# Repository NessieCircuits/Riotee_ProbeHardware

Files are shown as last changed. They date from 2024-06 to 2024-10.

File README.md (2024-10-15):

# Riotee Probe Hardware Design Files



The Riotee probe lets you program a Riotee module that is soldered onto your PCB or plugged into a breadboard. It has a standard 10-pin 0.1" connector compatible with the popular Tag-Connect cables that allow in-circuit debugging with a very small footprint.

Latest design files:
 - [Schematics](https://www.riotee.nessie-circuits.de/artifacts/probe_hardware/latest/schematics.pdf)
 - [Layout](https://www.riotee.nessie-circuits.de/artifacts/probe_hardware/latest/pcb.pdf)
 - [Assembly plan](https://www.riotee.nessie-circuits.de/artifacts/probe_hardware/latest/assembly.pdf)
 - [3D rendering](https://www.riotee.nessie-circuits.de/artifacts/probe_hardware/latest/3drendering.png)
 - [Gerber](https://www.riotee.nessie-circuits.de/artifacts/probe_hardware/latest/gerber.zip)
 - [BOM](https://www.riotee.nessie-circuits.de/artifacts/probe_hardware/latest/bom.csv)

Specification:
 - Custom debug probe for in-circuit programming/debugging of Riotee modules
 - USB-C connector for connection to a PC
 - Raspberry Pi RP2040 controller handles programming/debugging
 - CMSIS-DAP compatible: Supports programming of the Riotee module via pyOCD/OpenOCD
 - Makes UART output from Riotee module available via USB

Rendering of Riotee probe Riotee probe

## Firmware

The probe has a dedicated controller (Raspberry Pi RP2040) that manages the upload of new firmware to the Riotee device as well as the communication with a PC. The firmware running on the RP2040 is hosted in [this repository](https://github.com/NessieCircuits/Riotee_ProbeFirmware). To upgrade the firmware on the Riotee probe, connect a wire from one of the ground pins to the test pad labelled 'USB_BOOT' on the bottom of the board, while plugging in the USB cable. A removable storage drive should appear on your PC. Drop a UF2 compatible binary into the drive.

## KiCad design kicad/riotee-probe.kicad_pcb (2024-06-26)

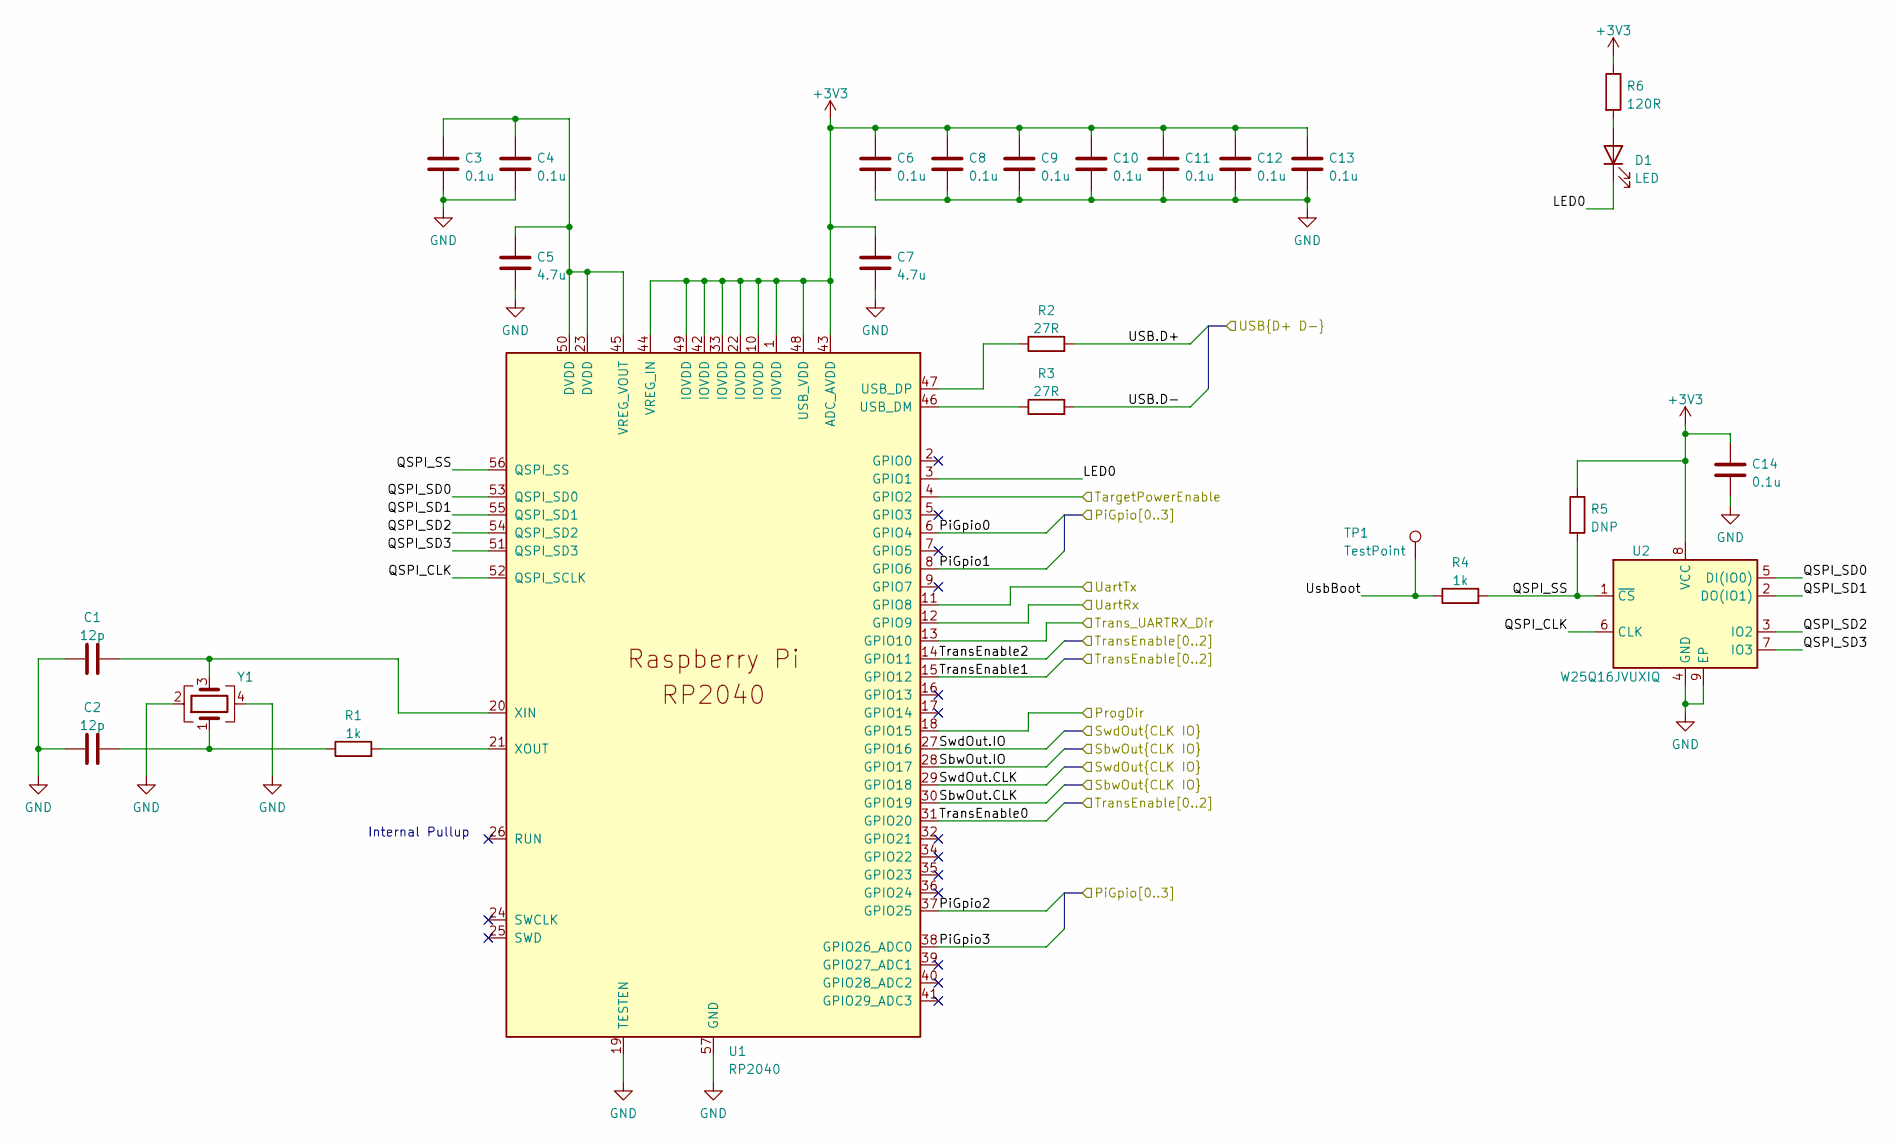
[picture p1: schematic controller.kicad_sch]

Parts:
C1, C2: 12p; C_0402_1005Metric; MPN 04025A120JAT2A
C3, C4, C6, C8, C9, C10, C11, C12, C13, C14: 0.1u; C_0402_1005Metric; MPN CL05A104KA5NNNC
C5, C7: 4.7u; C_0402_1005Metric; MPN CL05A475MP5NRNC
D1: LED; LED_0402_1005Metric; MPN QBLP595-AG1
R1, R4: 1k; R_0402_1005Metric; MPN WR04X1001FTL
R2, R3: 27R; R_0402_1005Metric; MPN CR0402-FX-27R0GLF
R5: DNP; R_0402_1005Metric
R6: 120R; R_0402_1005Metric; MPN CR0402-FX-1200GLF
TP1: TestPoint; TestPoint_Pad_D1.0mm
U1: RP2040; RP_RP2040; MPN RP2040
U2: W25Q16JVUXIQ; WB_UX8; MPN W25Q16JVUXIQ
Y1: Crystal_GND24; RALTRON_RH100; MPN RH100-12.000-18-2030-TR

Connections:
+3V3: C6.1, C7.1, C8.1, C9.1, C10.1, C11.1, C12.1, C13.1, C14.1, R5.1, R6.1, U1.1 (IOVDD), U1.10 (IOVDD), U1.22 (IOVDD), U1.33 (IOVDD), U1.42 (IOVDD), U1.43 (ADC_AVDD), U1.44 (VREG_IN), U1.48 (USB_VDD), U1.49 (IOVDD), U2.8 (VCC); also elsewhere on the board
/Connectors/PiGpio0: U1.6 (GPIO4); also elsewhere on the board
/Connectors/PiGpio1: U1.8 (GPIO6); also elsewhere on the board
/Connectors/PiGpio2: U1.37 (GPIO25); also elsewhere on the board
/Connectors/PiGpio3: U1.38 (GPIO26_ADC0); also elsewhere on the board
/Connectors/TargetPowerEnable: U1.4 (GPIO2); also elsewhere on the board
/Controller/LED0: D1.1 (K), U1.3 (GPIO1)
/Controller/ProgDir: U1.18 (GPIO15); also elsewhere on the board
/Controller/QSPI_CLK: U1.52 (QSPI_SCLK), U2.6 (CLK)
/Controller/QSPI_SD0: U1.53 (QSPI_SD0), U2.5 (DI(IO0))
/Controller/QSPI_SD1: U1.55 (QSPI_SD1), U2.2 (DO(IO1))
/Controller/QSPI_SD2: U1.54 (QSPI_SD2), U2.3 (IO2)
/Controller/QSPI_SD3: U1.51 (QSPI_SD3), U2.7 (IO3)
/Controller/QSPI_SS: R4.2, R5.2, U1.56 (QSPI_SS), U2.1 (~CS)
/Controller/SbwOut.CLK: U1.30 (GPIO19); also elsewhere on the board
/Controller/SbwOut.IO: U1.28 (GPIO17); also elsewhere on the board
/Controller/SwdOut.CLK: U1.29 (GPIO18); also elsewhere on the board
/Controller/SwdOut.IO: U1.27 (GPIO16); also elsewhere on the board
/Controller/TransEnable0: U1.31 (GPIO20); also elsewhere on the board
/Controller/TransEnable1: U1.15 (GPIO12); also elsewhere on the board
/Controller/TransEnable2: U1.14 (GPIO11); also elsewhere on the board
/Controller/Trans_UARTRX_Dir: U1.13 (GPIO10); also elsewhere on the board
/Controller/USB.D+: R2.2; also elsewhere on the board
/Controller/USB.D-: R3.2; also elsewhere on the board
/Controller/UartRx: U1.12 (GPIO9); also elsewhere on the board
/Controller/UartTx: U1.11 (GPIO8); also elsewhere on the board
/Controller/UsbBoot: R4.1, TP1.1
GND: C1.1, C2.2, C3.2, C4.2, C5.2, C6.2, C7.2, C8.2, C9.2, C10.2, C11.2, C12.2, C13.2, C14.2, U1.19 (TESTEN), U1.57 (GND), U2.4 (GND), U2.9 (EP), Y1.2, Y1.4; also elsewhere on the board
unnamed: C2.1, R1.1, Y1.1
unnamed: D1.2 (A), R6.2
unnamed: R3.1, U1.46 (USB_DM)
unnamed: R2.1, U1.47 (USB_DP)
unnamed: C3.1, C4.1, C5.1, U1.23 (DVDD), U1.45 (VREG_VOUT), U1.50 (DVDD)
unnamed: C1.2, U1.20 (XIN), Y1.3
unnamed: R1.2, U1.21 (XOUT)

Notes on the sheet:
Internal Pullup

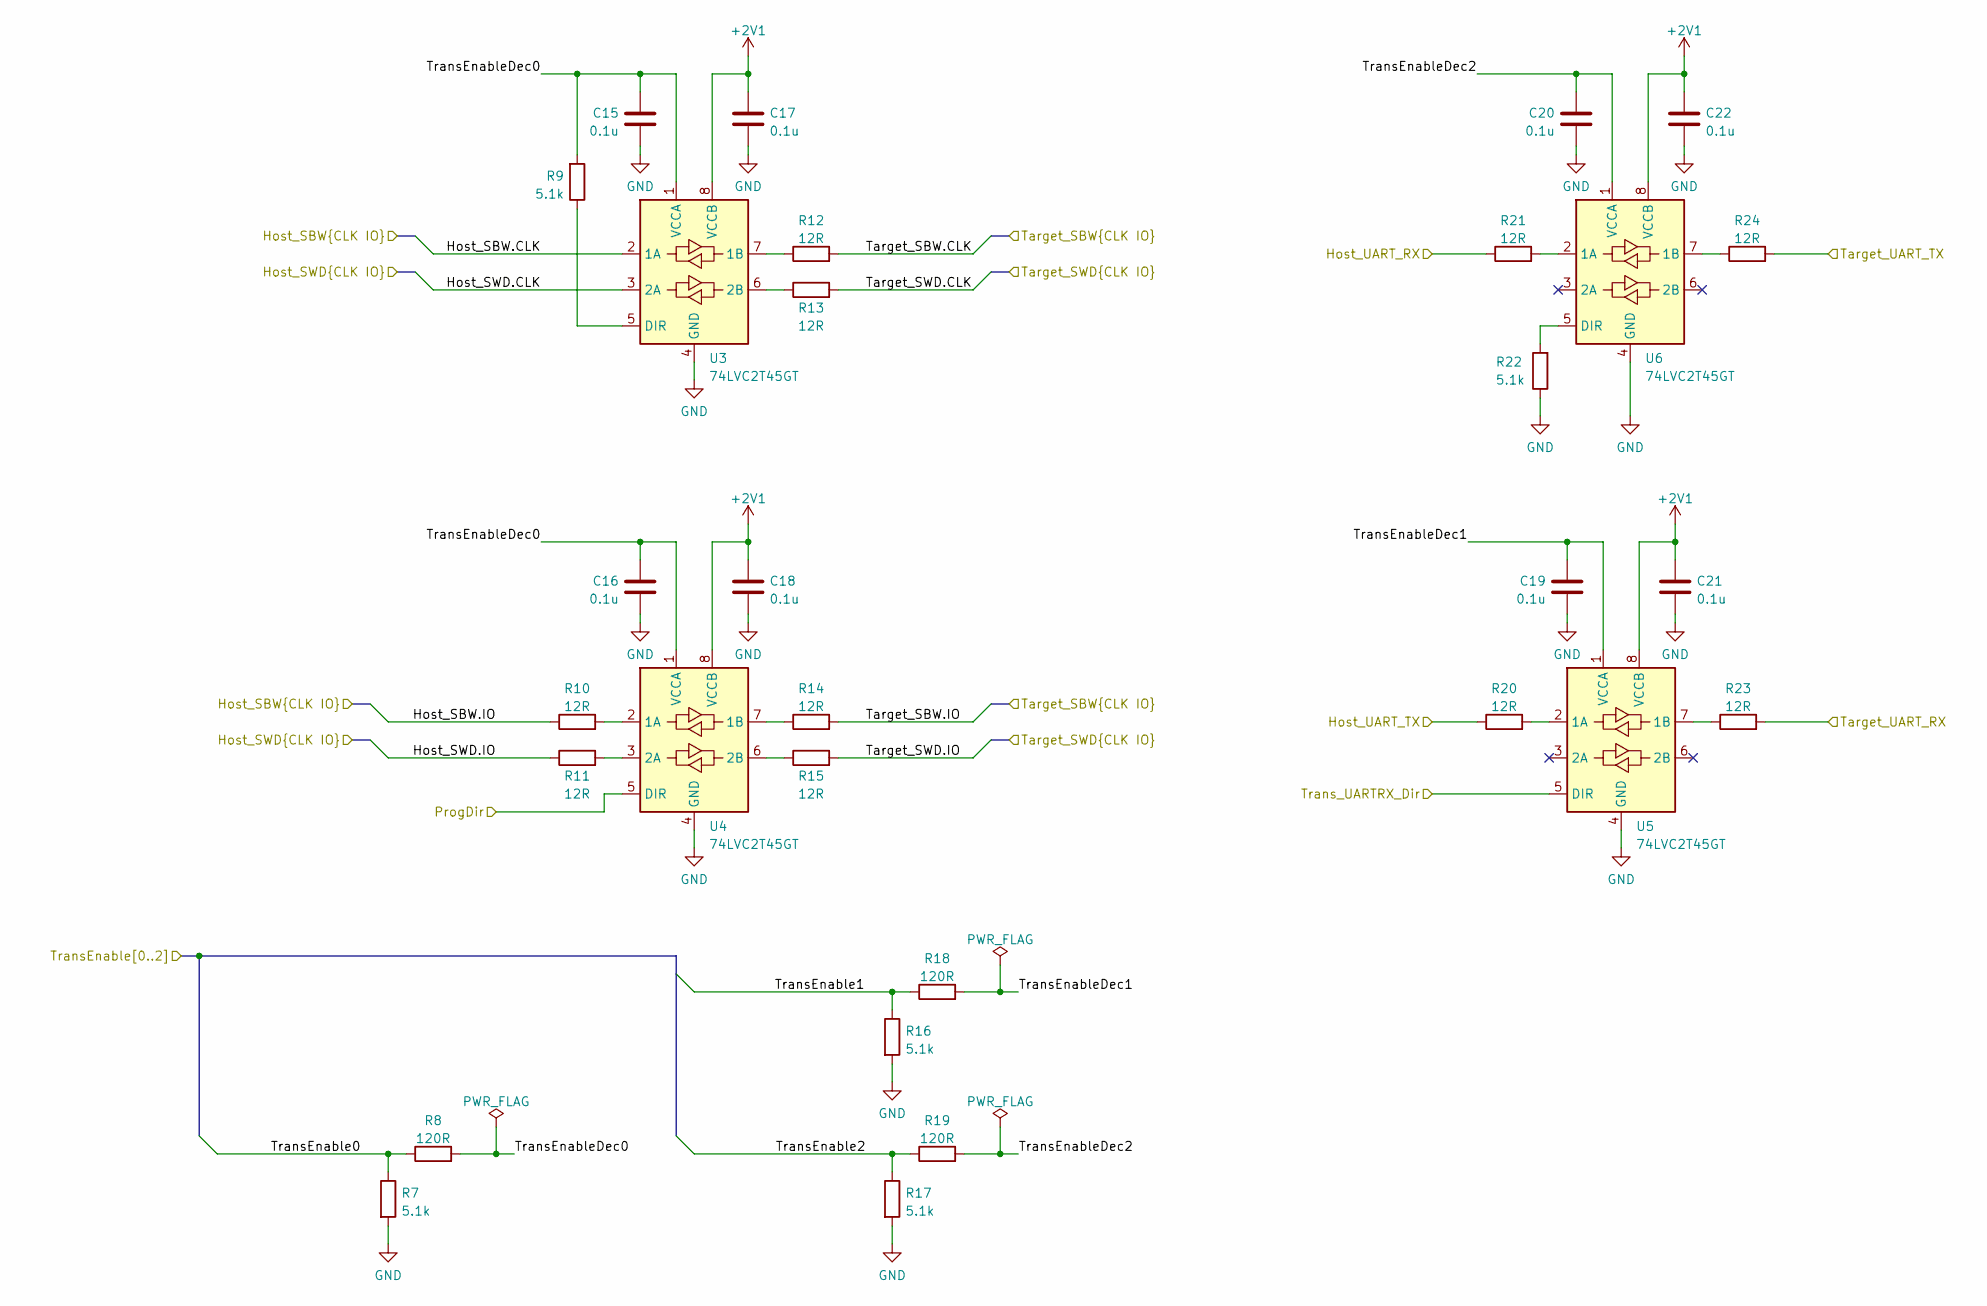
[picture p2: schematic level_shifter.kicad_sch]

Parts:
C15, C16, C17, C18, C19, C20, C21, C22: 0.1u; C_0402_1005Metric; MPN CL05A104KA5NNNC
R7, R9, R16, R17, R22: 5.1k; R_0402_1005Metric; MPN CR0402-FX-5101GLF
R8, R18, R19: 120R; R_0402_1005Metric; MPN CR0402-FX-1200GLF
R10, R11, R12, R13, R14, R15, R20, R21, R23, R24: 12R; R_0402_1005Metric; MPN RMCF0402FT12R0
U3, U4, U5, U6: 74LVC2T45GT; NXP_SOT833-1; MPN 74LVC2T45GT,115

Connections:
+2V1: C17.1, C18.1, C21.1, C22.1, U3.8 (VCCB), U4.8 (VCCB), U5.8 (VCCB), U6.8 (VCCB); also elsewhere on the board
/Connectors/Target_SBW.CLK: R12.2; also elsewhere on the board
/Connectors/Target_SBW.IO: R14.2; also elsewhere on the board
/Connectors/Target_SWD.CLK: R13.2; also elsewhere on the board
/Connectors/Target_SWD.IO: R15.2; also elsewhere on the board
/Connectors/Target_UART_RX: R23.2; also elsewhere on the board
/Connectors/Target_UART_TX: R24.2; also elsewhere on the board
/Controller/ProgDir: U4.5 (DIR); also elsewhere on the board
/Controller/SbwOut.CLK: U3.2 (1A); also elsewhere on the board
/Controller/SbwOut.IO: R10.1; also elsewhere on the board
/Controller/SwdOut.CLK: U3.3 (2A); also elsewhere on the board
/Controller/SwdOut.IO: R11.1; also elsewhere on the board
/Controller/TransEnable0: R7.1, R8.1; also elsewhere on the board
/Controller/TransEnable1: R16.1, R18.1; also elsewhere on the board
/Controller/TransEnable2: R17.1, R19.1; also elsewhere on the board
/Controller/Trans_UARTRX_Dir: U5.5 (DIR); also elsewhere on the board
/Controller/UartRx: R21.1; also elsewhere on the board
/Controller/UartTx: R20.1; also elsewhere on the board
/LevelShifter/TransEnableDec0: C15.2, C16.2, R8.2, R9.2, U3.1 (VCCA), U4.1 (VCCA)
/LevelShifter/TransEnableDec1: C19.2, R18.2, U5.1 (VCCA)
/LevelShifter/TransEnableDec2: C20.2, R19.2, U6.1 (VCCA)
GND: C15.1, C16.1, C17.2, C18.2, C19.1, C20.1, C21.2, C22.2, R7.2, R16.2, R17.2, R22.1, U3.4 (GND), U4.4 (GND), U5.4 (GND), U6.4 (GND); also elsewhere on the board
unnamed: R12.1, U3.7 (1B)
unnamed: R13.1, U3.6 (2B)
unnamed: R9.1, U3.5 (DIR)
unnamed: R10.2, U4.2 (1A)
unnamed: R14.1, U4.7 (1B)
unnamed: R11.2, U4.3 (2A)
unnamed: R15.1, U4.6 (2B)
unnamed: R20.2, U5.2 (1A)
unnamed: R23.1, U5.7 (1B)
unnamed: R21.2, U6.2 (1A)
unnamed: R24.1, U6.7 (1B)
unnamed: R22.2, U6.5 (DIR)

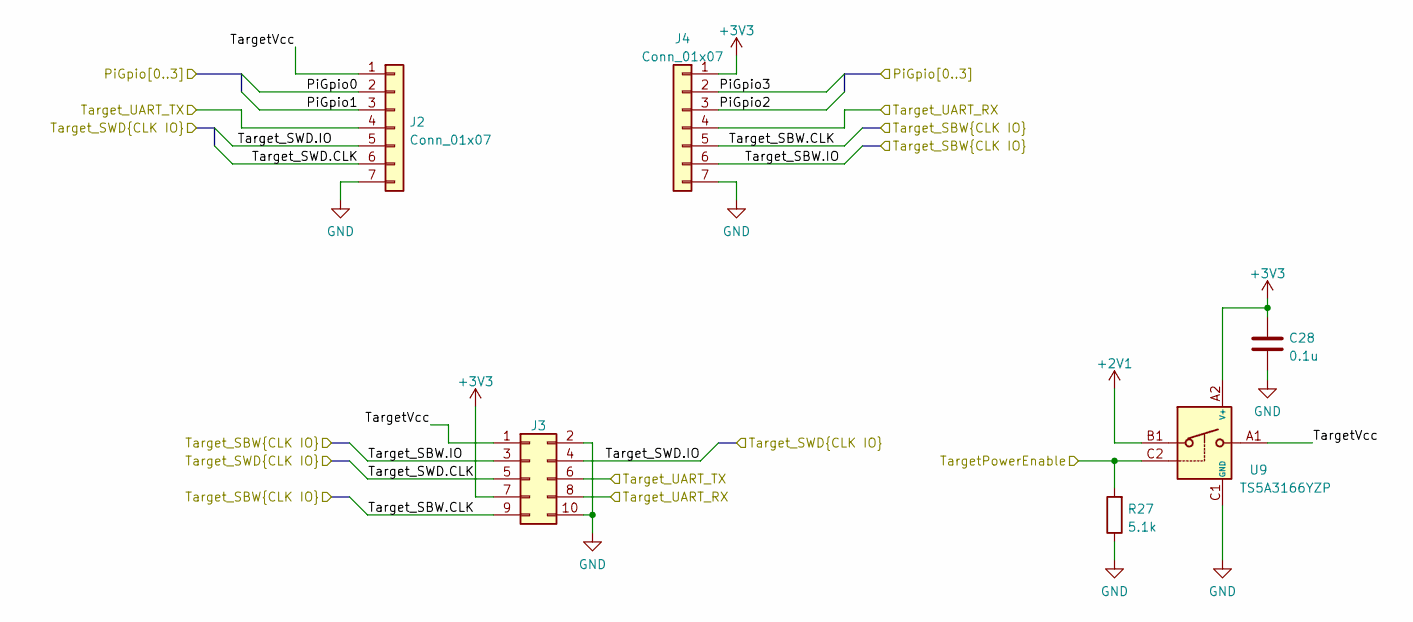
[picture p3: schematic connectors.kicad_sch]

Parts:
C28: 0.1u; C_0402_1005Metric; MPN CL05A104KA5NNNC
J2, J4: Conn_01x07; PinHeader_1x07_P2.54mm_Plain
J3: Conn_02x05_Odd_Even; IDC-Header_2x05_P2.54mm_Vertical_SMD; MPN AWHW 10G-SMD
R27: 5.1k; R_0402_1005Metric; MPN CR0402-FX-5101GLF
U9: TS5A3166YZP; TI_YZP0005; MPN TS5A3166YZP

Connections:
+2V1: U9.B1; also elsewhere on the board
+3V3: C28.1, J3.7, J4.1, U9.A2 (V+); also elsewhere on the board
/Connectors/PiGpio0: J2.2; also elsewhere on the board
/Connectors/PiGpio1: J2.3; also elsewhere on the board
/Connectors/PiGpio2: J4.3; also elsewhere on the board
/Connectors/PiGpio3: J4.2; also elsewhere on the board
/Connectors/TargetPowerEnable: R27.2, U9.C2; also elsewhere on the board
/Connectors/TargetVcc: J2.1, J3.1, U9.A1
/Connectors/Target_SBW.CLK: J3.9, J4.5; also elsewhere on the board
/Connectors/Target_SBW.IO: J3.3, J4.6; also elsewhere on the board
/Connectors/Target_SWD.CLK: J2.6, J3.5; also elsewhere on the board
/Connectors/Target_SWD.IO: J2.5, J3.4; also elsewhere on the board
/Connectors/Target_UART_RX: J3.8, J4.4; also elsewhere on the board
/Connectors/Target_UART_TX: J2.4, J3.6; also elsewhere on the board
GND: C28.2, J2.7, J3.2, J3.10, J4.7, R27.1, U9.C1 (GND); also elsewhere on the board

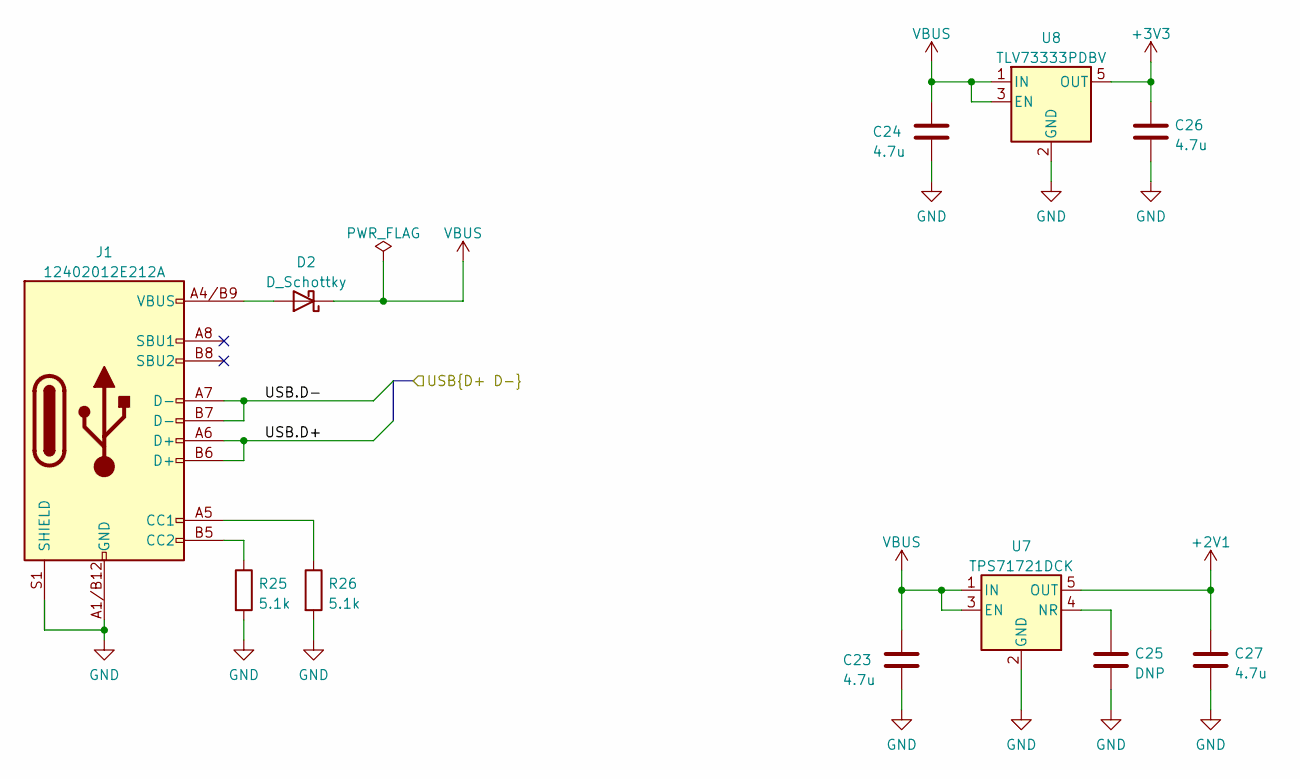
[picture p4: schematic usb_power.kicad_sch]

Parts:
C23, C24, C26, C27: 4.7u; C_0402_1005Metric; MPN CL05A475MP5NRNC
C25: DNP; C_0402_1005Metric
D2: D_Schottky; D_SOD-523; MPN RB521S30T1G
J1: 12402012E212A; AMPH_12402012E212A; MPN 12402012E212A
R25, R26: 5.1k; R_0402_1005Metric; MPN CR0402-FX-5101GLF
U7: TPS71721DCK; TI_DCK0005A; MPN TPS71721DCK
U8: TLV73333PDBV; TI_DBV0005A; MPN TLV73333PDBV

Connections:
+2V1: C27.1, U7.5 (OUT); also elsewhere on the board
+3V3: C26.1, U8.5 (OUT); also elsewhere on the board
/Controller/USB.D+: J1.A6 (D+), J1.B6 (D+); also elsewhere on the board
/Controller/USB.D-: J1.A7 (D-), J1.B7 (D-); also elsewhere on the board
GND: C23.2, C24.2, C25.2, C26.2, C27.2, J1.A1/B12 (GND), J1.B1/A12 (GND), J1.S1 (SHIELD), R25.2, R26.2, U7.2 (GND), U8.2 (GND); also elsewhere on the board
unnamed: D2.2 (A), J1.A4/B9 (VBUS), J1.B4/A9 (VBUS)
unnamed: J1.A5 (CC1), R26.1
unnamed: J1.B5 (CC2), R25.1
unnamed: C25.1, U7.4 (NR)
VBUS: C23.1, C24.1, D2.1 (K), U7.1 (IN), U7.3 (EN), U8.1 (IN), U8.3 (EN)

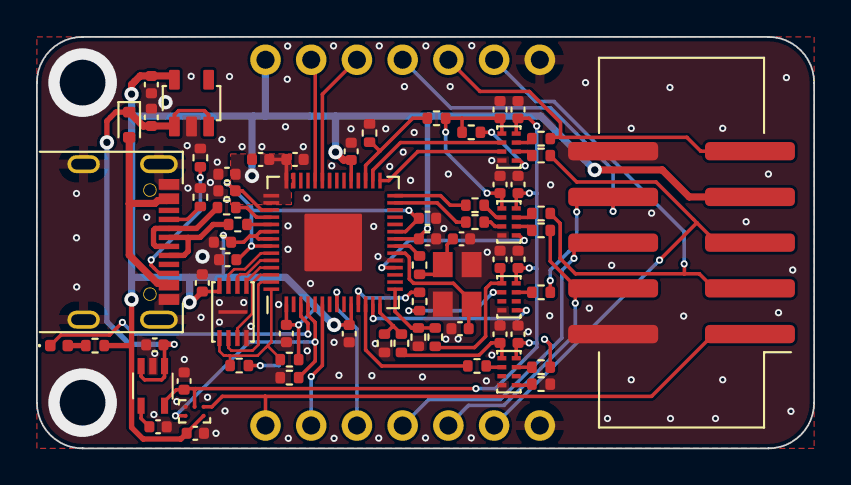
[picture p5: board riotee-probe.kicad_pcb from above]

Board: 4 copper layers, 43.2 x 22.9 mm, 72 parts (1 on the bottom side), 63 nets.

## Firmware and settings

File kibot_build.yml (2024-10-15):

kibot:
  version: 1

preflight:
  check_zone_fills: true
  erc:
    filters:
    - filter: 'ignore simulation errors'
      error: 'simulation_model_issue'
  drc: true

outputs:
  # PDF Schematic Print (Portable Document Format):
  # This is the main format to document your schematic.
  # This output is what you get from the 'File/Print' menu in eeschema.
  - name: 'pdf_sch_print'
    comment: 'Exports schematics to PDF'
    type: 'pdf_sch_print'
    dir: '.'
    options:
      # [string='%f-%i%I%v.%x'] Filename for the output PDF (%i=schematic, %x=pdf). Affected by global options
      output: 'schematics.%x'

  - name: 'pcb_print'
    comment: 'Prints the PCB'
    type: 'pcb_print'
    dir: '.'
    options:
      # [number=0] Default horizontal margin used for the autoscaling mode [mm]
      autoscale_margin_x: 15
      # [number=0] Default vertical margin used for the autoscaling mode [mm]
      autoscale_margin_y: 15
      # [boolean=false] Add the `Edge.Cuts` to all the pages
      force_edge_cuts: true
      # [string='PDF'] [PDF,SVG,PNG,EPS,PS] Format for the output file/s.
      # Note that for PS you need `ghostscript` which isn't part of the default docker images
      format: 'PDF'
      # [string='%f-%i%I%v.%x'] Filename for the output (%i=assembly, %x=pdf/ps)/(%i=assembly_page_NN, %x=svg/png/eps).
      # Consult the `page_number_as_extension` and `page_id` options. Affected by global options
      output: 'pcb.%x'
      # [list(dict)] List of pages to include in the output document.
      # Each page contains one or more layers of the PCB
      pages:
        # [number=1.0] Scale factor (0 means autoscaling)
        - scaling: 0
          # [list(dict)|list(string)|string] List of layers printed in this page.
          # Order is important, the last goes on top.
          # You can reuse other layers lists, some options aren't used here, but they are valid
          layers:
            - 'F.Cu'
          # [string='Assembly'] Text to use for the `sheet` in the title block
          sheet: 'Top Copper'
        # [number=1.0] Scale factor (0 means autoscaling)
        - scaling: 0
          # [list(dict)|list(string)|string] List of layers printed in this page.
          # Order is important, the last goes on top.
          # You can reuse other layers lists, some options aren't used here, but they are valid
          layers:
            - 'B.Cu'
          # [string='Assembly'] Text to use for the `sheet` in the title block
          sheet: 'Bottom Copper'
        # [number=1.0] Scale factor (0 means autoscaling)
        - scaling: 0
          # [list(dict)|list(string)|string] List of layers printed in this page.
          # Order is important, the last goes on top.
          # You can reuse other layers lists, some options aren't used here, but they are valid
          layers:
            - 'F.Mask'
          # [string='Assembly'] Text to use for the `sheet` in the title block
          sheet: 'Top Solder Mask'
          # [number=1.0] Scale factor (0 means autoscaling)
        - scaling: 0
          # [list(dict)|list(string)|string] List of layers printed in this page.
          # Order is important, the last goes on top.
          # You can reuse other layers lists, some options aren't used here, but they are valid
          layers:
            - 'B.Mask'
          # [string='Assembly'] Text to use for the `sheet` in the title block
          sheet: 'Bottom Solder Mask'
          # [number=1.0] Scale factor (0 means autoscaling)
        - scaling: 0
          # [list(dict)|list(string)|string] List of layers printed in this page.
          # Order is important, the last goes on top.
          # You can reuse other layers lists, some options aren't used here, but they are valid
          layers:
            - 'B.Silkscreen'
          # [string='Assembly'] Text to use for the `sheet` in the title block
          sheet: 'Bottom Silkscreen'
          # [number=1.0] Scale factor (0 means autoscaling)
        - scaling: 0
          # [list(dict)|list(string)|string] List of layers printed in this page.
          # Order is important, the last goes on top.
          # You can reuse other layers lists, some options aren't used here, but they are valid
          layers:
            - 'F.Paste'
          # [string='Assembly'] Text to use for the `sheet` in the title block
          sheet: 'Top Stencil'
      # [number=1280] [0,7680] Width of the PNG in pixels. Use 0 to use as many pixels as the DPI needs for the page size
      png_width: 1280
      # [number=1.0] Default scale factor (0 means autoscaling)
      scaling: 0
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

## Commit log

2023-01-19 update kicad library
2023-01-19 update board footprints
    [riotee-probe.kicad_pcb]
2023-01-22 add fourth level converter for simultaneous programming + TX/RX
    [connectors.kicad_sch, controller.kicad_sch, level_shifter.kicad_sch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]
2023-01-31 add assembly plan to CI/CD build
    [riotee-probe.kicad_pcb]
2023-02-02 adjust values of level translator series resistors
    [level_shifter.kicad_sch, riotee-probe.kicad_pcb, riotee-probe.kicad_sch]
2023-02-20 replace target supply diode with analog switch
    [connectors.kicad_sch, controller.kicad_sch, level_shifter.kicad_sch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]
2023-02-20 add MPNs in schematics
    [connectors.kicad_sch, controller.kicad_sch, level_shifter.kicad_sch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]
2023-02-21 fix pulldown value
    [connectors.kicad_sch, riotee-probe.kicad_pcb, riotee-probe.kicad_sch]
2023-04-05 change to 4 layer board
    [connectors.kicad_sch, riotee-probe.kicad_pcb, riotee-probe.kicad_sch]
2023-04-10 update footprints and add component description to BOM
    [connectors.kicad_sch, controller.kicad_sch, level_shifter.kicad_sch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]
2023-04-14 add conformity marks and refine BOM settings
    [connectors.kicad_sch, controller.kicad_sch, riotee-probe.kicad_pcb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]
2023-04-15 fix position of one pin header
    [riotee-probe.kicad_pcb]
2023-05-06 migrate project to kicad 7
    [connectors.kicad_sch, controller.kicad_sch, level_shifter.kicad_sch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]
2024-06-26 update to kicad 8
    [connectors.kicad_sch, controller.kicad_sch, level_shifter.kicad_sch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]
2024-10-15 generate bom and gerber in github workflow with kibot
